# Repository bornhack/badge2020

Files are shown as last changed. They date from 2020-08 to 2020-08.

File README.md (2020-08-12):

# Bornhack Badge 2020

## About the hardware

Similar to the last couple of years, this badge has an ARM cortex M0+ as the main
controller, but on this badge it's the SAMD21 from Microchip, with 4 times as much
flash and RAM compared to the chips from the previous badges.

This makes it possible to run Adafruit CircuitPython on this badge, which lowers the
bar for how easy it is to get started hacking on the badge, since all you need is a
USB cable to connect it to your computer and an editor (vi, nano, VSCode, notepad,
you name it) to change the `code.py` file on the badge. No need to have a tool chain
installed on your computer, it's all happening on the badge when you save the file.

## Features

- The main feature of the badge is a 9x32 pixel LED matrix controlled by 2
IS31FL3731 LED controllers, that control the LEDs via charlieplexing
- The other primary feature is an infrared LED to transmit and an infrared receiver
and decoder to receive badge to badge communication
- There are also 4 navigation/game buttons and a reset button
- The badge is either powered by 2xAA batteries, that have the voltage boosted to
3.3v or via USB, where the voltage is regulated down to 3.3v
- The main controller is a SAMD21G18A with a GD25Q32C (4MB SPI flash) connected
for libraries, graphics, etc.
- There is also an unpopulated header for Shitty Add On v.1.69bis
- On the back of the badge, all i/o pins that are not used on the microcontroller
is pull out to small SMD pads for optional soldering on add-ons or similar.

## Getting started

To start making your badge your own, you can connect it via USB and a mass storage
device should show up with a `code.py` file in the root directory.

If you open that file in your favorite text editor you will find a few lines first
that loads some libraries, then some initialisation of the LED drivers and on line 20
you will find an assignment of a string variable with the scrolling text shown on
the LED matrix. To put eg. your name on the badge, you can change this text and save
the file, and after a few seconds, the badge will restart the code and your text
should be slowly scrolling across the "screen".

If you have gotten this far you are up and running with your first "hack" of the
2020 BornHack badge and you can continue with more elaborate hacking.

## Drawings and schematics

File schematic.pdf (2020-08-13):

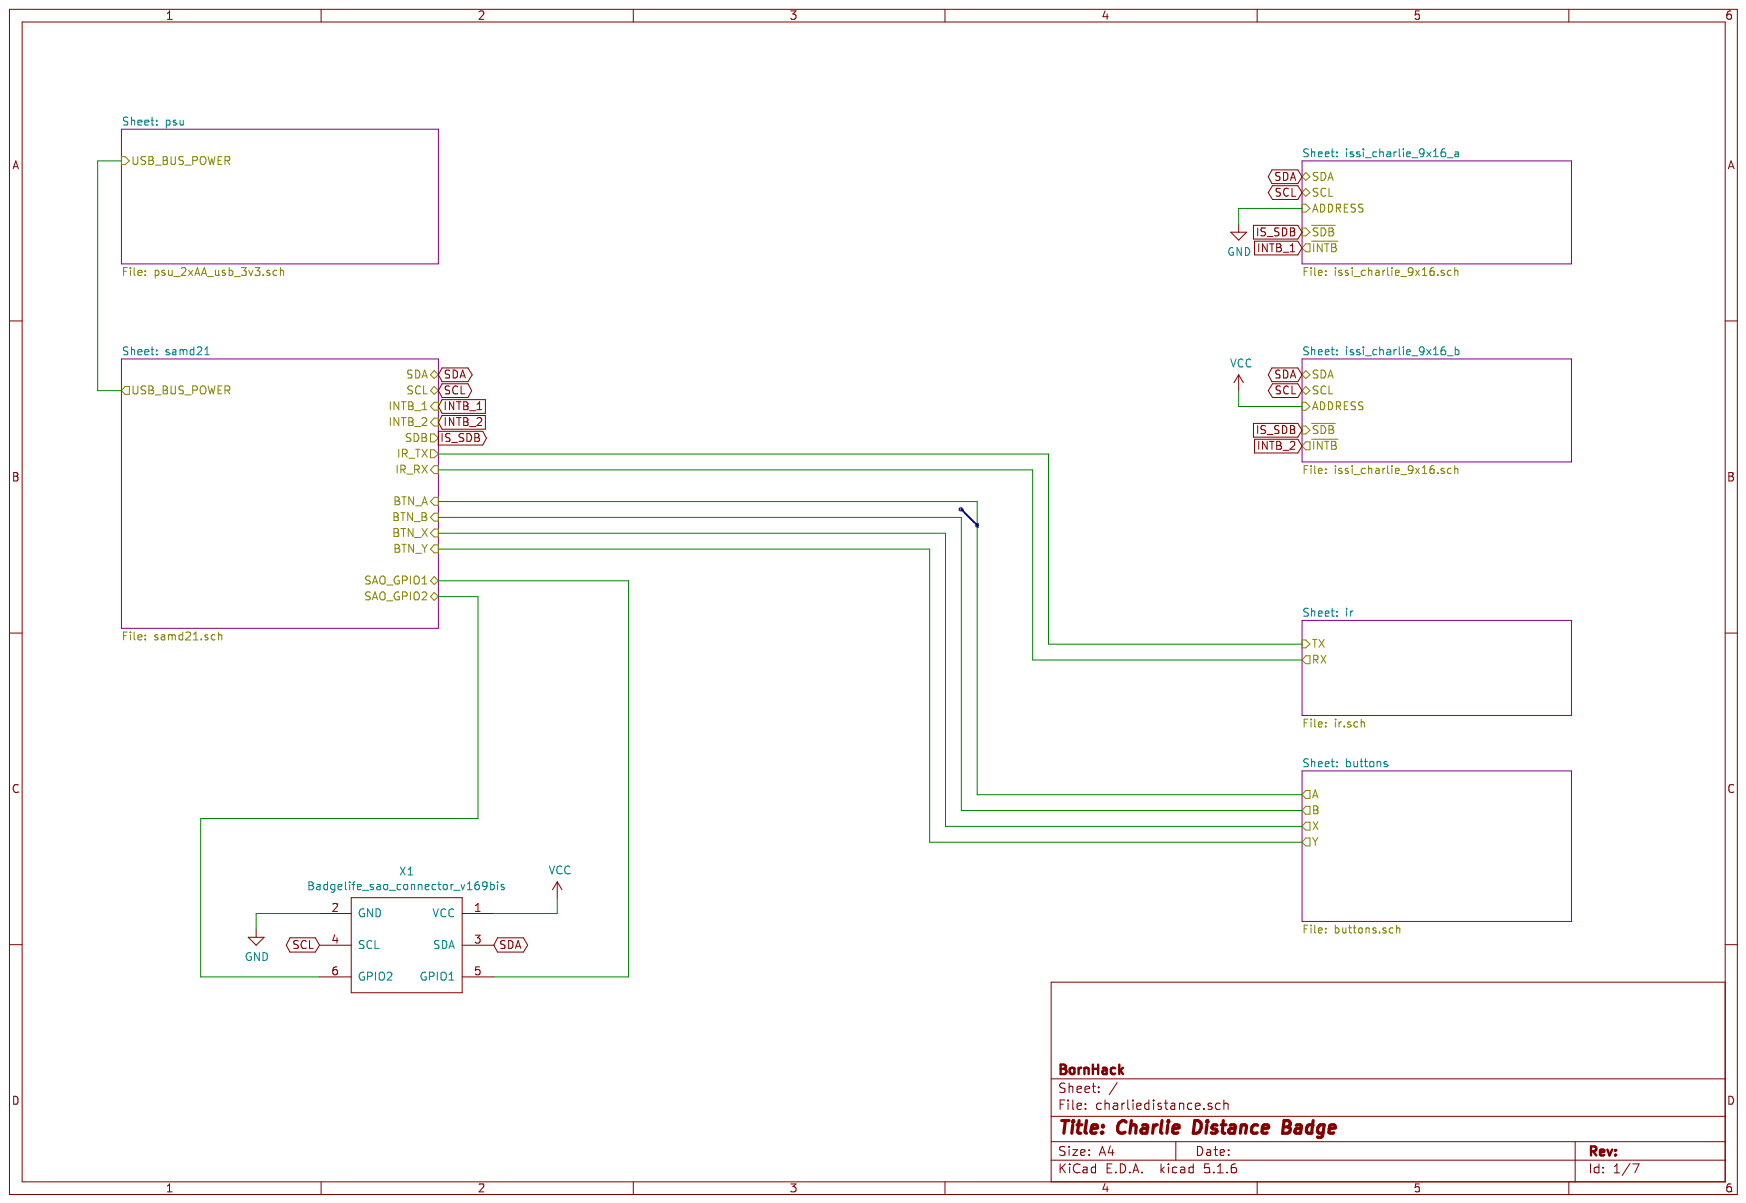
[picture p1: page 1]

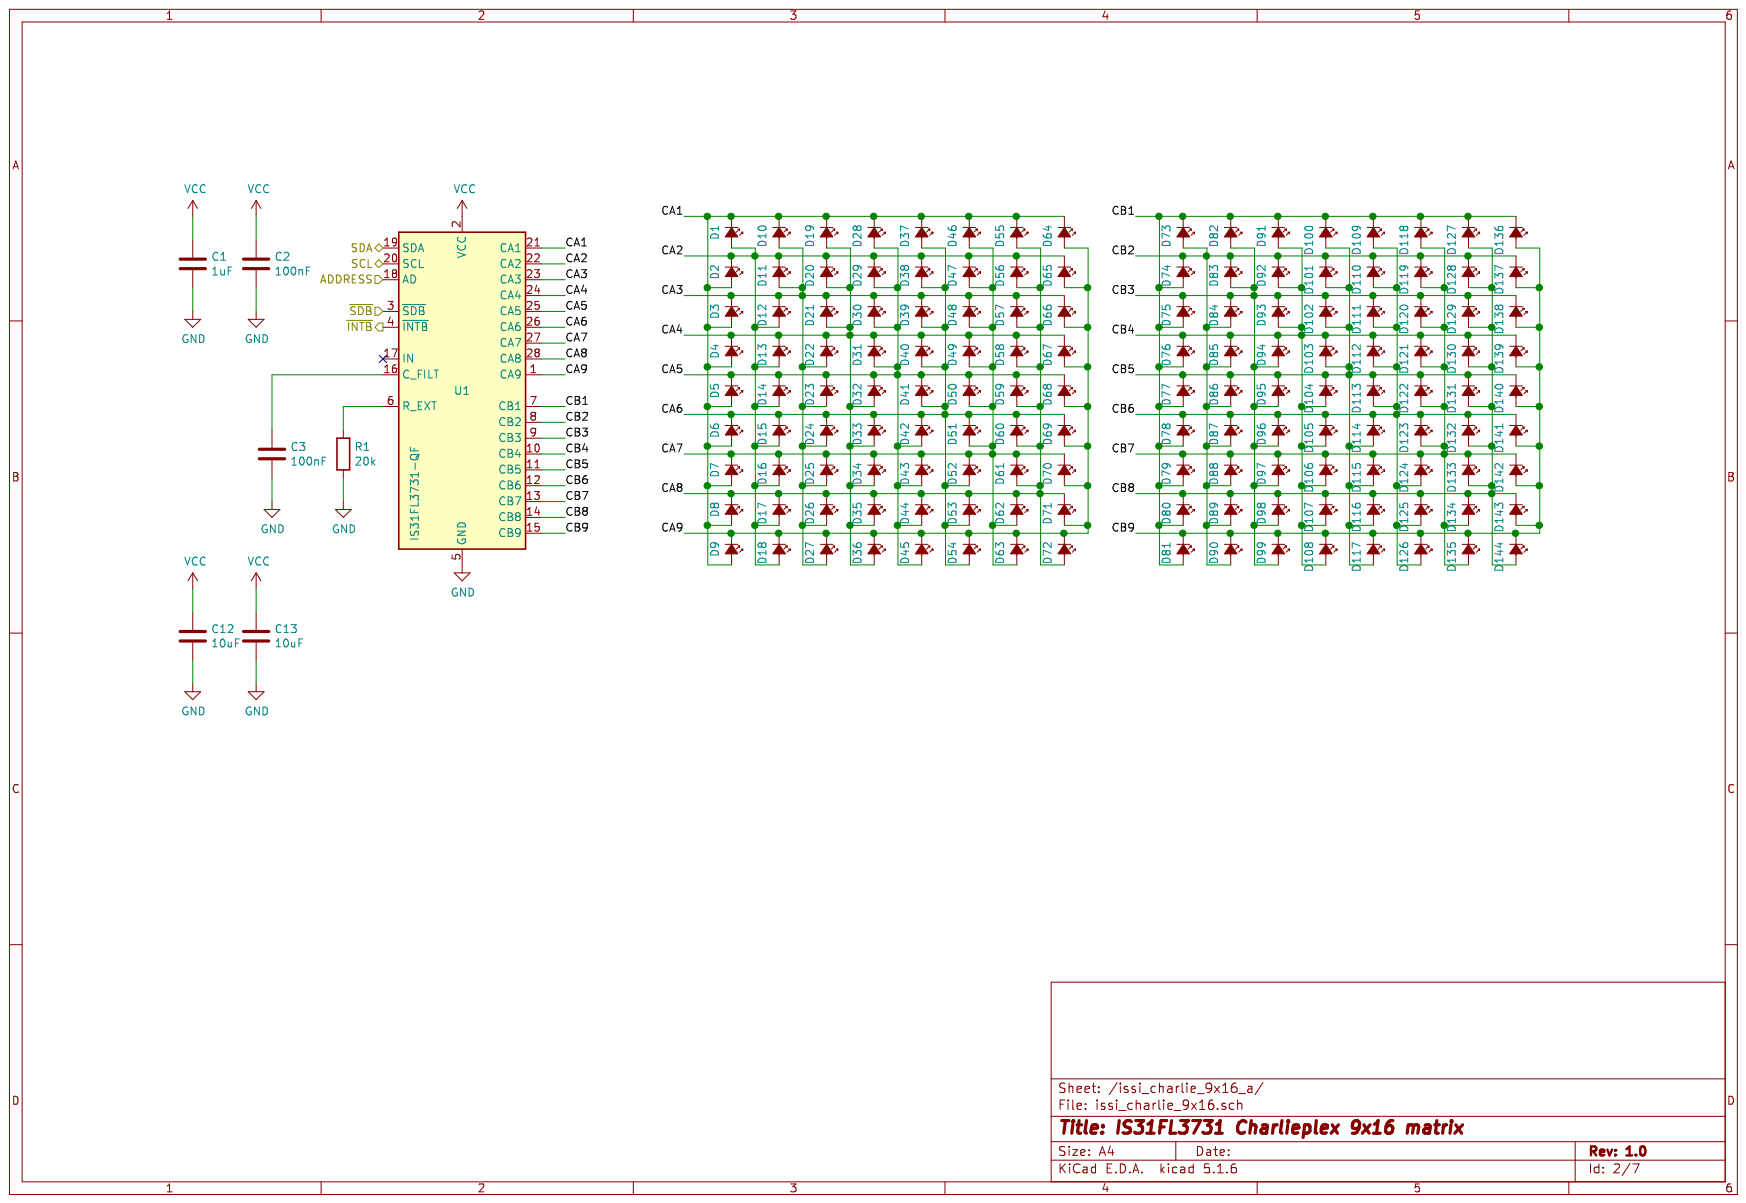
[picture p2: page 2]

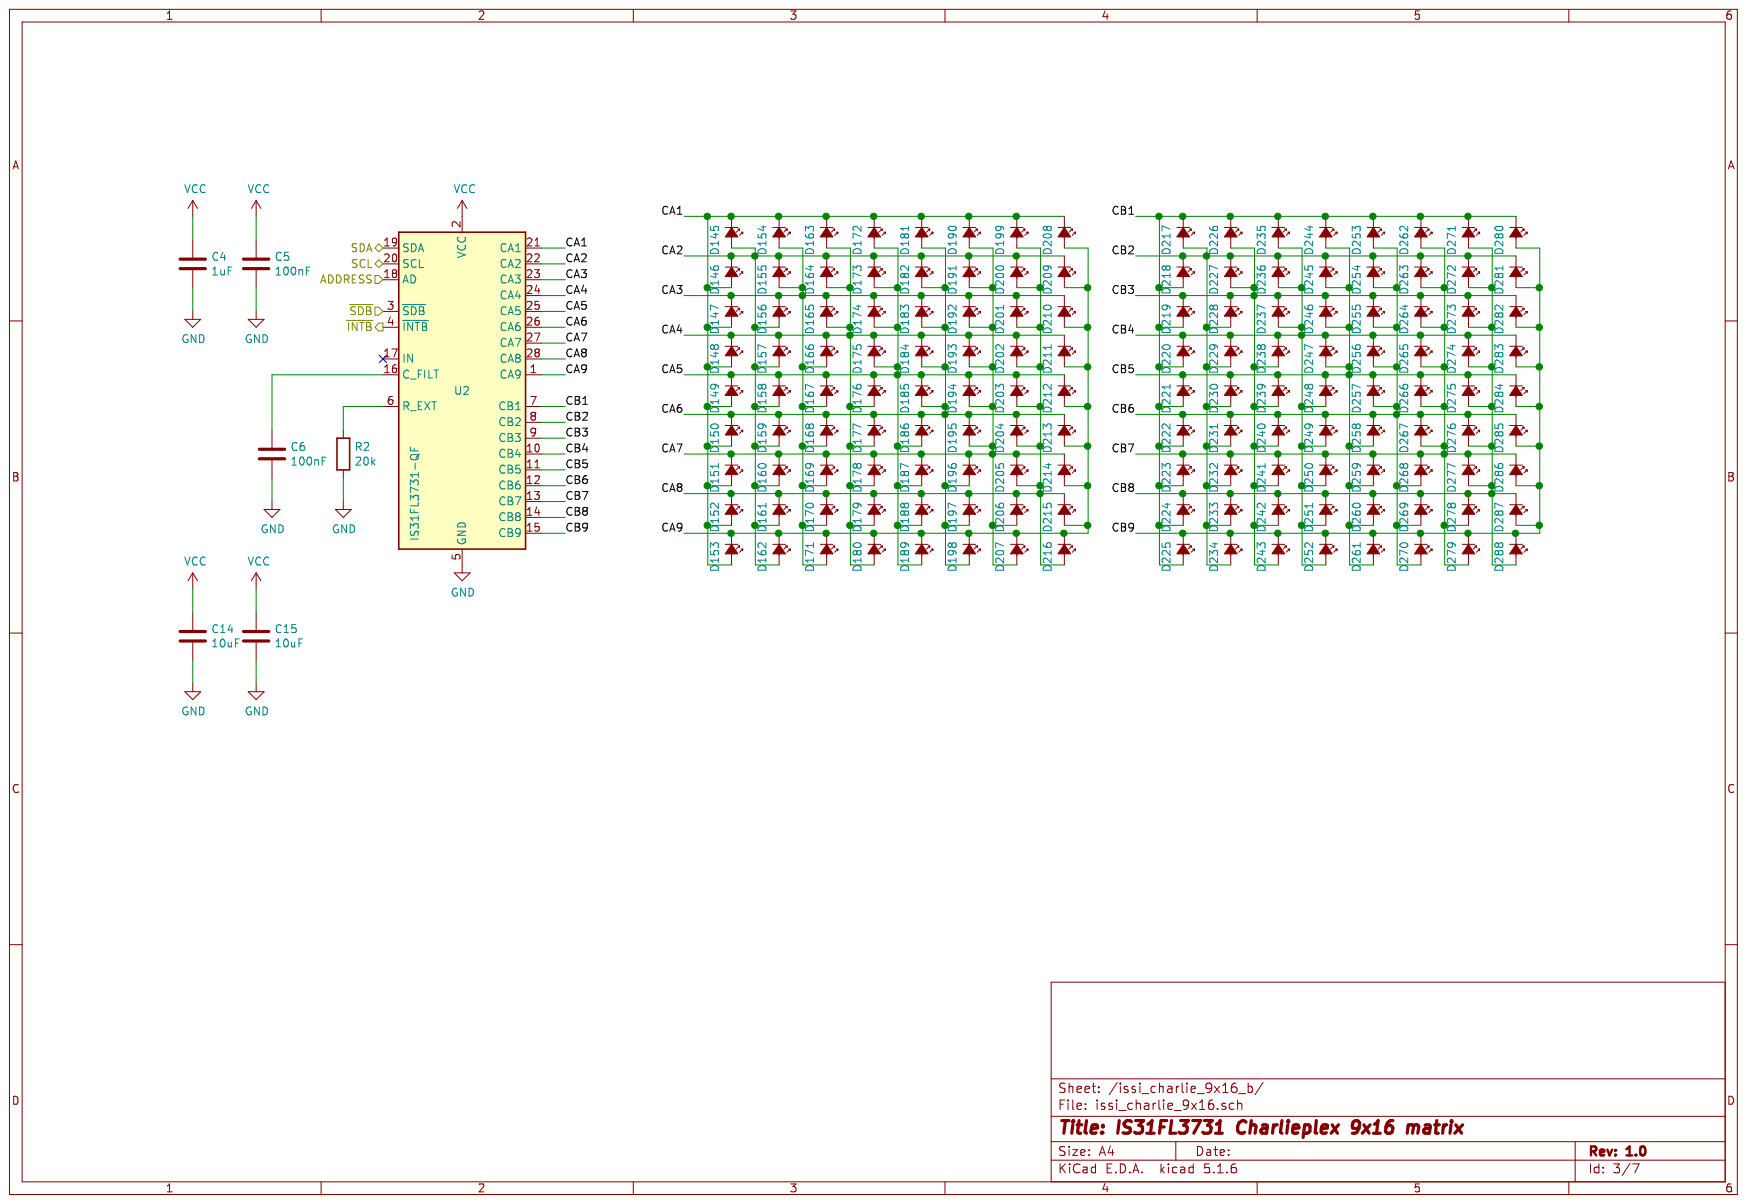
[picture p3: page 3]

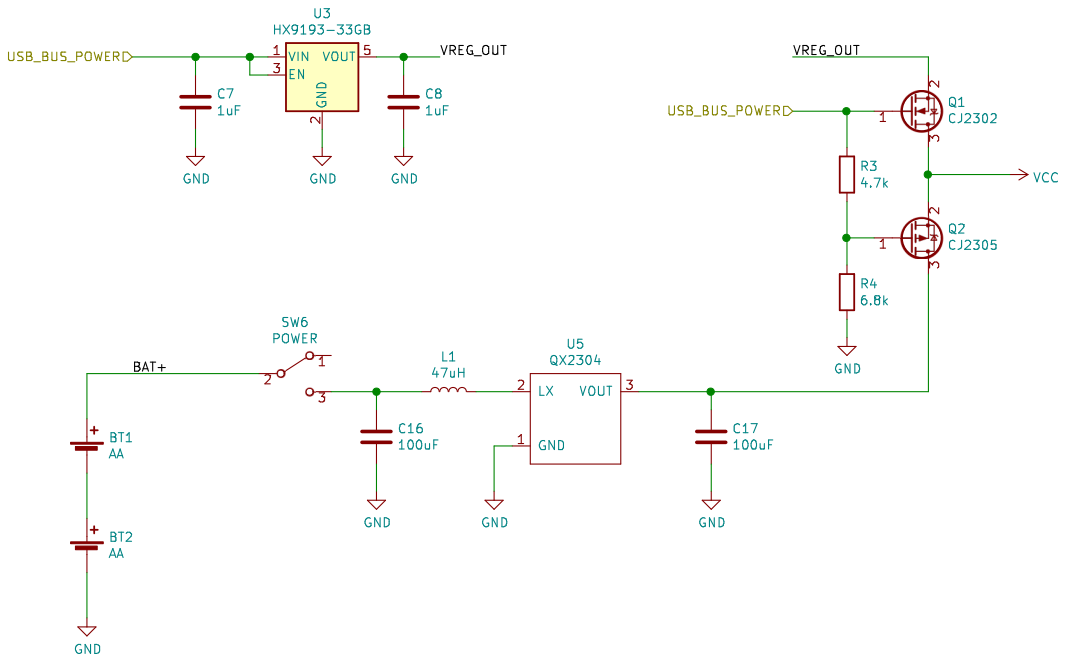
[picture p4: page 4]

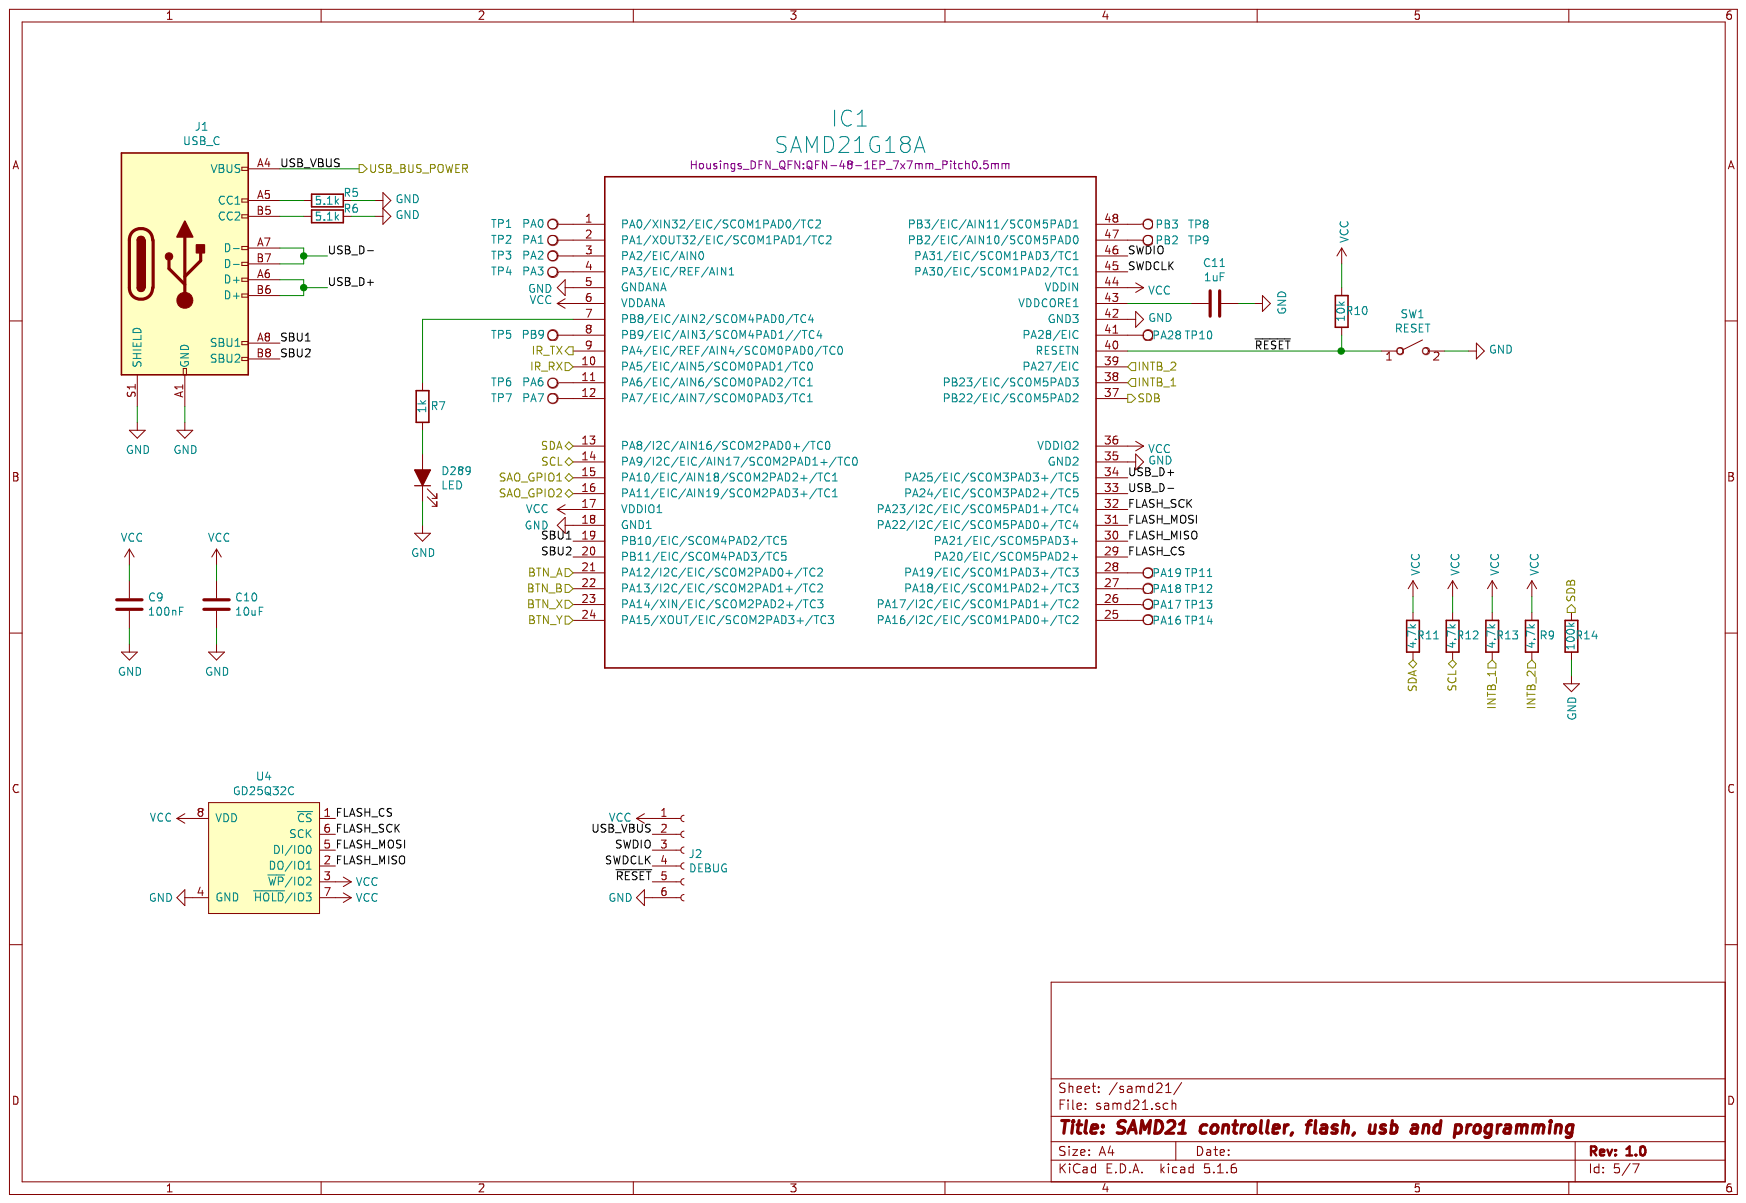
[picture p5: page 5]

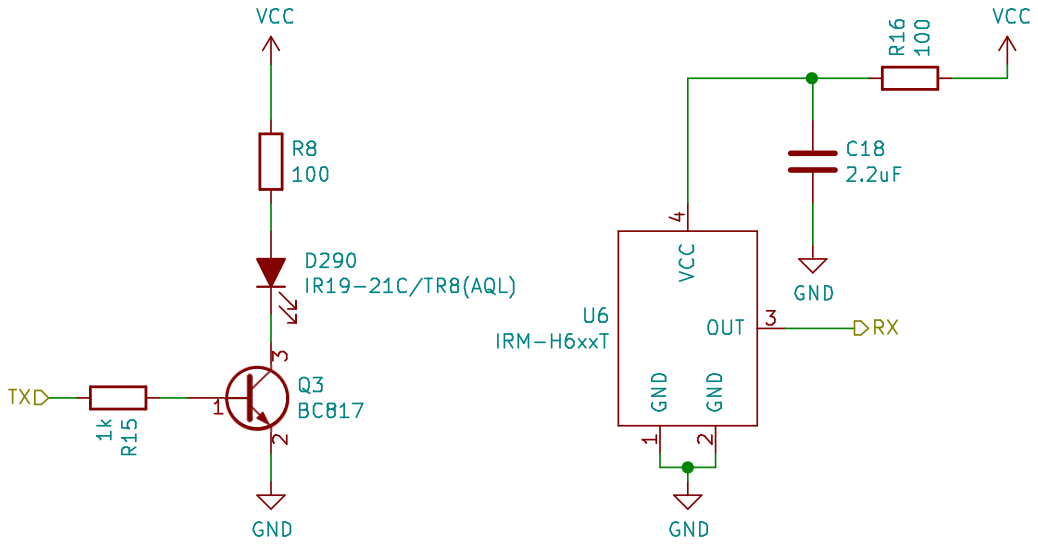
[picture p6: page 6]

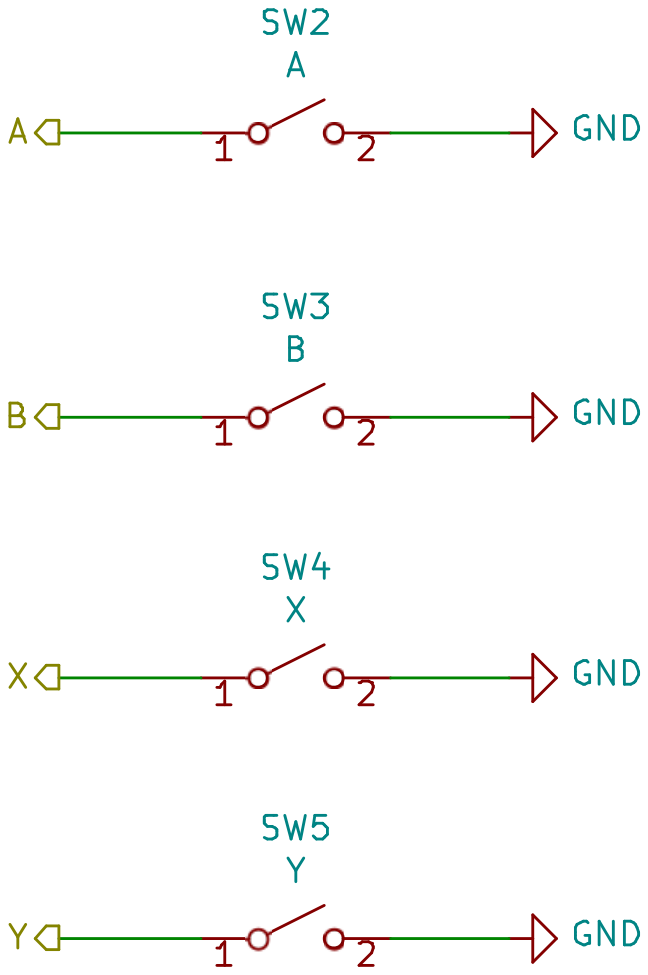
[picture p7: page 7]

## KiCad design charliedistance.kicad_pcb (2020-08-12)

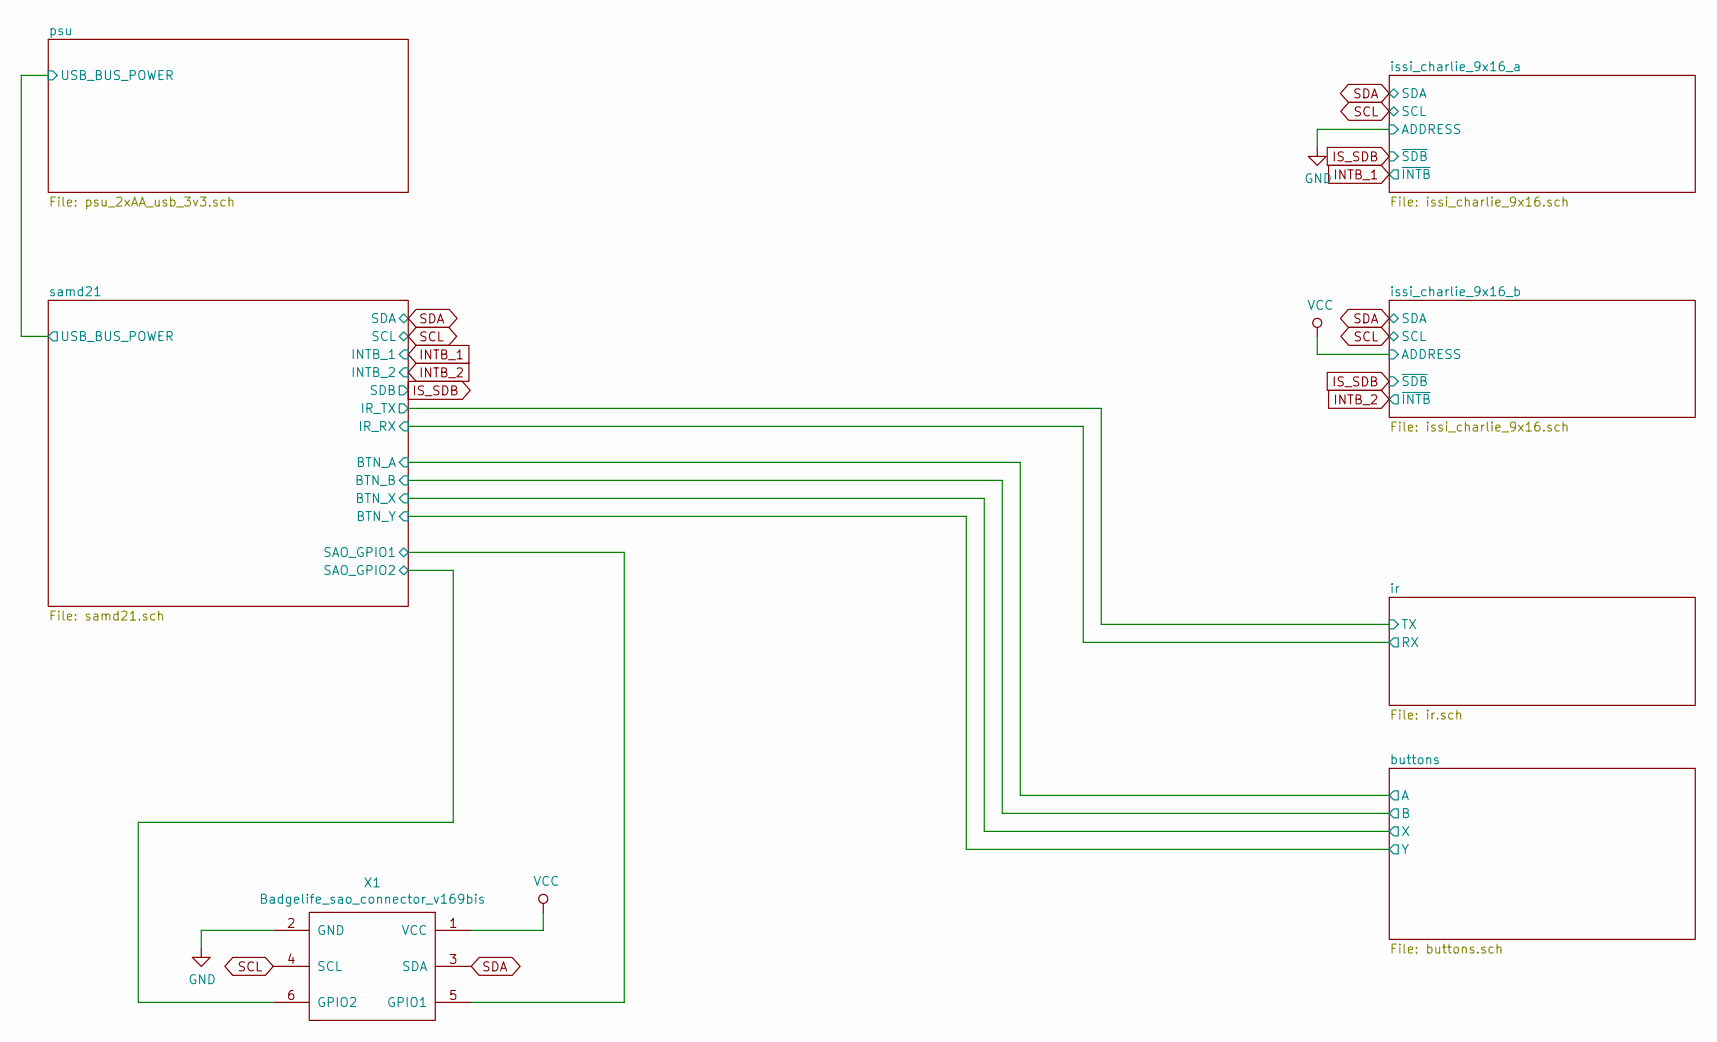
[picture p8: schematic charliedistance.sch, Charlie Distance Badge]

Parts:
X1: Badgelife_sao_connector_v169bis; Badgelife-SAOv169-BADGE-2x3

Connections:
/samd21/SAO_GPIO1: X1.5 (GPIO1); also elsewhere on the board
/samd21/SAO_GPIO2: X1.6 (GPIO2); also elsewhere on the board
GND: X1.2 (GND); also elsewhere on the board
SCL: X1.4 (SCL); also elsewhere on the board
SDA: X1.3 (SDA); also elsewhere on the board
VCC: X1.1 (VCC); also elsewhere on the board

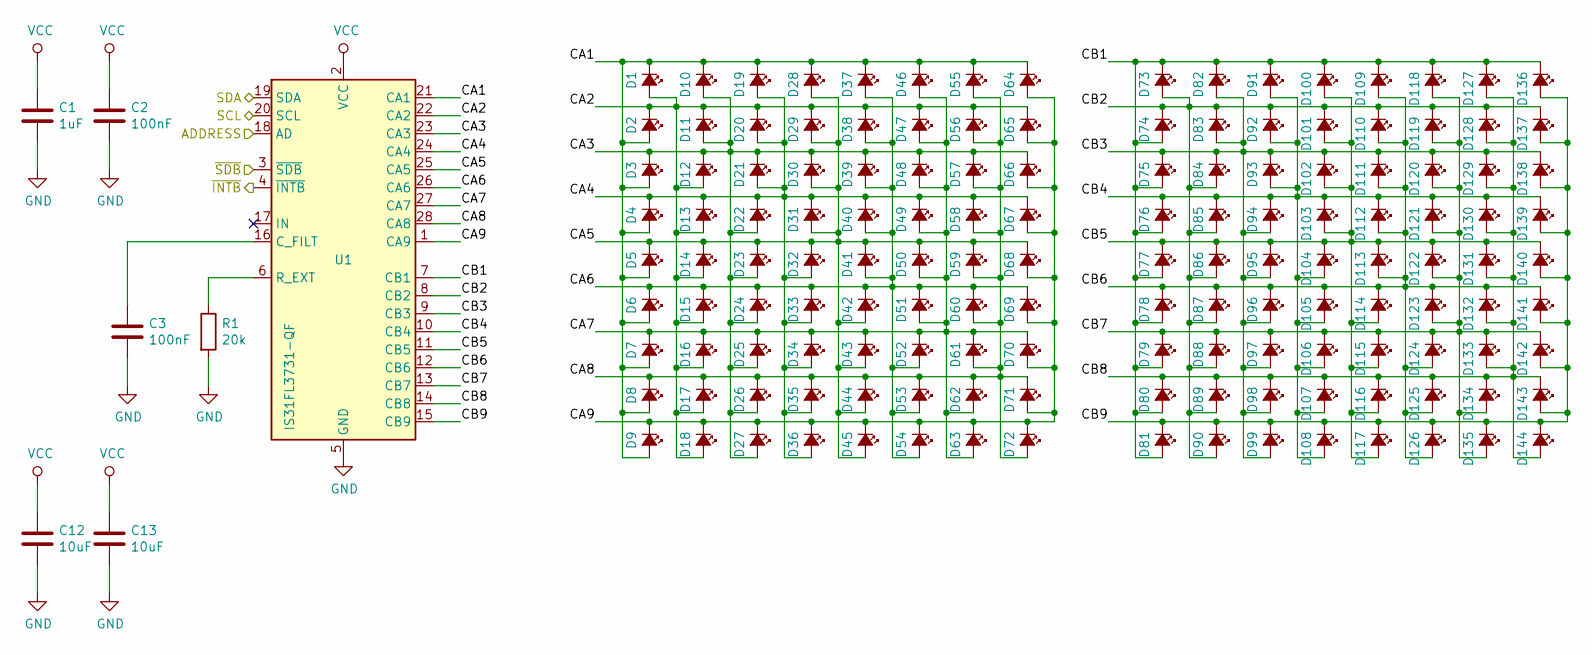
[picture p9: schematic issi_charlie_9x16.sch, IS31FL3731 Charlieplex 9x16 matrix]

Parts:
C1: 1uF; C_0603
C2, C3: 100nF; C_0603
C12, C13: 10uF; C_0603
D1, D2, D3, D4, D5, D6, D7, D8, D9, D10, D11, D12, D13, D14, D15, D16, D17, D18, D19, D20, D21, D22, D23, D24, D25, D26, D27, D28, D29, D30, D31, D32, D33, D34, D35, D36, D37, D38, D39, D40, D41, D42, D43, D44, D45, D46, D47, D48, D49, D50, D51, D52, D53, D54, D55, D56, D57, D58, D59, D60, D61, D62, D63, D64, D65, D66, D67, D68, D69, D70, D71, D72, D73, D74, D75, D76, D77, D78, D79, D80, D81, D82, D83, D84, D85, D86, D87, D88, D89, D90, D91, D92, D93, D94, D95, D96, D97, D98, D99, D100, D101, D102, D103, D104, D105, D106, D107, D108, D109, D110, D111, D112, D113, D114, D115, D116, D117, D118, D119, D120, D121, D122, D123, D124, D125, D126, D127, D128, D129, D130, D131, D132, D133, D134, D135, D136, D137, D138, D139, D140, D141, D142, D143, D144: LED_Small_ALT; LED_0603
R1: 20k; R_0603
U1: IS31FL3731-QF; QFN-28-1EP_4x4mm_Pitch0.4mm

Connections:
/issi_charlie_9x16_a/CA1: D1.1 (K), D2.2 (A), D3.2 (A), D4.2 (A), D5.2 (A), D6.2 (A), D7.2 (A), D8.2 (A), D9.2 (A), D10.1 (K), D19.1 (K), D28.1 (K), D37.1 (K), D46.1 (K), D55.1 (K), D64.1 (K), U1.21 (CA1)
/issi_charlie_9x16_a/CA2: D1.2 (A), D2.1 (K), D11.1 (K), D12.2 (A), D13.2 (A), D14.2 (A), D15.2 (A), D16.2 (A), D17.2 (A), D18.2 (A), D20.1 (K), D29.1 (K), D38.1 (K), D47.1 (K), D56.1 (K), D65.1 (K), U1.22 (CA2)
/issi_charlie_9x16_a/CA3: D3.1 (K), D10.2 (A), D11.2 (A), D12.1 (K), D21.1 (K), D22.2 (A), D23.2 (A), D24.2 (A), D25.2 (A), D26.2 (A), D27.2 (A), D30.1 (K), D39.1 (K), D48.1 (K), D57.1 (K), D66.1 (K), U1.23 (CA3)
/issi_charlie_9x16_a/CA4: D4.1 (K), D13.1 (K), D19.2 (A), D20.2 (A), D21.2 (A), D22.1 (K), D31.1 (K), D32.2 (A), D33.2 (A), D34.2 (A), D35.2 (A), D36.2 (A), D40.1 (K), D49.1 (K), D58.1 (K), D67.1 (K), U1.24 (CA4)
/issi_charlie_9x16_a/CA5: D5.1 (K), D14.1 (K), D23.1 (K), D28.2 (A), D29.2 (A), D30.2 (A), D31.2 (A), D32.1 (K), D41.1 (K), D42.2 (A), D43.2 (A), D44.2 (A), D45.2 (A), D50.1 (K), D59.1 (K), D68.1 (K), U1.25 (CA5)
/issi_charlie_9x16_a/CA6: D6.1 (K), D15.1 (K), D24.1 (K), D33.1 (K), D37.2 (A), D38.2 (A), D39.2 (A), D40.2 (A), D41.2 (A), D42.1 (K), D51.1 (K), D52.2 (A), D53.2 (A), D54.2 (A), D60.1 (K), D69.1 (K), U1.26 (CA6)
/issi_charlie_9x16_a/CA7: D7.1 (K), D16.1 (K), D25.1 (K), D34.1 (K), D43.1 (K), D46.2 (A), D47.2 (A), D48.2 (A), D49.2 (A), D50.2 (A), D51.2 (A), D52.1 (K), D61.1 (K), D62.2 (A), D63.2 (A), D70.1 (K), U1.27 (CA7)
/issi_charlie_9x16_a/CA8: D8.1 (K), D17.1 (K), D26.1 (K), D35.1 (K), D44.1 (K), D53.1 (K), D55.2 (A), D56.2 (A), D57.2 (A), D58.2 (A), D59.2 (A), D60.2 (A), D61.2 (A), D62.1 (K), D71.1 (K), D72.2 (A), U1.28 (CA8)
/issi_charlie_9x16_a/CA9: D9.1 (K), D18.1 (K), D27.1 (K), D36.1 (K), D45.1 (K), D54.1 (K), D63.1 (K), D64.2 (A), D65.2 (A), D66.2 (A), D67.2 (A), D68.2 (A), D69.2 (A), D70.2 (A), D71.2 (A), D72.1 (K), U1.1 (CA9)
/issi_charlie_9x16_a/CB1: D73.1 (K), D74.2 (A), D75.2 (A), D76.2 (A), D77.2 (A), D78.2 (A), D79.2 (A), D80.2 (A), D81.2 (A), D82.1 (K), D91.1 (K), D100.1 (K), D109.1 (K), D118.1 (K), D127.1 (K), D136.1 (K), U1.7 (CB1)
/issi_charlie_9x16_a/CB2: D73.2 (A), D74.1 (K), D83.1 (K), D84.2 (A), D85.2 (A), D86.2 (A), D87.2 (A), D88.2 (A), D89.2 (A), D90.2 (A), D92.1 (K), D101.1 (K), D110.1 (K), D119.1 (K), D128.1 (K), D137.1 (K), U1.8 (CB2)
/issi_charlie_9x16_a/CB3: D75.1 (K), D82.2 (A), D83.2 (A), D84.1 (K), D93.1 (K), D94.2 (A), D95.2 (A), D96.2 (A), D97.2 (A), D98.2 (A), D99.2 (A), D102.1 (K), D111.1 (K), D120.1 (K), D129.1 (K), D138.1 (K), U1.9 (CB3)
/issi_charlie_9x16_a/CB4: D76.1 (K), D85.1 (K), D91.2 (A), D92.2 (A), D93.2 (A), D94.1 (K), D103.1 (K), D104.2 (A), D105.2 (A), D106.2 (A), D107.2 (A), D108.2 (A), D112.1 (K), D121.1 (K), D130.1 (K), D139.1 (K), U1.10 (CB4)
/issi_charlie_9x16_a/CB5: D77.1 (K), D86.1 (K), D95.1 (K), D100.2 (A), D101.2 (A), D102.2 (A), D103.2 (A), D104.1 (K), D113.1 (K), D114.2 (A), D115.2 (A), D116.2 (A), D117.2 (A), D122.1 (K), D131.1 (K), D140.1 (K), U1.11 (CB5)
/issi_charlie_9x16_a/CB6: D78.1 (K), D87.1 (K), D96.1 (K), D105.1 (K), D109.2 (A), D110.2 (A), D111.2 (A), D112.2 (A), D113.2 (A), D114.1 (K), D123.1 (K), D124.2 (A), D125.2 (A), D126.2 (A), D132.1 (K), D141.1 (K), U1.12 (CB6)
/issi_charlie_9x16_a/CB7: D79.1 (K), D88.1 (K), D97.1 (K), D106.1 (K), D115.1 (K), D118.2 (A), D119.2 (A), D120.2 (A), D121.2 (A), D122.2 (A), D123.2 (A), D124.1 (K), D133.1 (K), D134.2 (A), D135.2 (A), D142.1 (K), U1.13 (CB7)
/issi_charlie_9x16_a/CB8: D80.1 (K), D89.1 (K), D98.1 (K), D107.1 (K), D116.1 (K), D125.1 (K), D127.2 (A), D128.2 (A), D129.2 (A), D130.2 (A), D131.2 (A), D132.2 (A), D133.2 (A), D134.1 (K), D143.1 (K), D144.2 (A), U1.14 (CB8)
/issi_charlie_9x16_a/CB9: D81.1 (K), D90.1 (K), D99.1 (K), D108.1 (K), D117.1 (K), D126.1 (K), D135.1 (K), D136.2 (A), D137.2 (A), D138.2 (A), D139.2 (A), D140.2 (A), D141.2 (A), D142.2 (A), D143.2 (A), D144.1 (K), U1.15 (CB9)
GND: C1.2, C2.2, C3.2, C12.2, C13.2, R1.2, U1.5 (GND), U1.18 (AD), U1.29 (GND); also elsewhere on the board
INTB_1: U1.4 (~INTB); also elsewhere on the board
IS_SDB: U1.3 (~SDB); also elsewhere on the board
unnamed: C3.1, U1.16 (C_FILT)
unnamed: R1.1, U1.6 (R_EXT)
SCL: U1.20 (SCL); also elsewhere on the board
SDA: U1.19 (SDA); also elsewhere on the board
VCC: C1.1, C2.1, C12.1, C13.1, U1.2 (VCC); also elsewhere on the board

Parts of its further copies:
C4: 1uF; C_0603
C5, C6: 100nF; C_0603
C14, C15: 10uF; C_0603
D145, D146, D147, D148, D149, D150, D151, D152, D153, D154, D155, D156, D157, D158, D159, D160, D161, D162, D163, D164, D165, D166, D167, D168, D169, D170, D171, D172, D173, D174, D175, D176, D177, D178, D179, D180, D181, D182, D183, D184, D185, D186, D187, D188, D189, D190, D191, D192, D193, D194, D195, D196, D197, D198, D199, D200, D201, D202, D203, D204, D205, D206, D207, D208, D209, D210, D211, D212, D213, D214, D215, D216, D217, D218, D219, D220, D221, D222, D223, D224, D225, D226, D227, D228, D229, D230, D231, D232, D233, D234, D235, D236, D237, D238, D239, D240, D241, D242, D243, D244, D245, D246, D247, D248, D249, D250, D251, D252, D253, D254, D255, D256, D257, D258, D259, D260, D261, D262, D263, D264, D265, D266, D267, D268, D269, D270, D271, D272, D273, D274, D275, D276, D277, D278, D279, D280, D281, D282, D283, D284, D285, D286, D287, D288: LED_Small_ALT; LED_0603
R2: 20k; R_0603
U2: IS31FL3731-QF; QFN-28-1EP_4x4mm_Pitch0.4mm

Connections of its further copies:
/issi_charlie_9x16_b/CA1: D145.1 (K), D146.2 (A), D147.2 (A), D148.2 (A), D149.2 (A), D150.2 (A), D151.2 (A), D152.2 (A), D153.2 (A), D154.1 (K), D163.1 (K), D172.1 (K), D181.1 (K), D190.1 (K), D199.1 (K), D208.1 (K), U2.21 (CA1)
/issi_charlie_9x16_b/CA2: D145.2 (A), D146.1 (K), D155.1 (K), D156.2 (A), D157.2 (A), D158.2 (A), D159.2 (A), D160.2 (A), D161.2 (A), D162.2 (A), D164.1 (K), D173.1 (K), D182.1 (K), D191.1 (K), D200.1 (K), D209.1 (K), U2.22 (CA2)
/issi_charlie_9x16_b/CA3: D147.1 (K), D154.2 (A), D155.2 (A), D156.1 (K), D165.1 (K), D166.2 (A), D167.2 (A), D168.2 (A), D169.2 (A), D170.2 (A), D171.2 (A), D174.1 (K), D183.1 (K), D192.1 (K), D201.1 (K), D210.1 (K), U2.23 (CA3)
/issi_charlie_9x16_b/CA4: D148.1 (K), D157.1 (K), D163.2 (A), D164.2 (A), D165.2 (A), D166.1 (K), D175.1 (K), D176.2 (A), D177.2 (A), D178.2 (A), D179.2 (A), D180.2 (A), D184.1 (K), D193.1 (K), D202.1 (K), D211.1 (K), U2.24 (CA4)
/issi_charlie_9x16_b/CA5: D149.1 (K), D158.1 (K), D167.1 (K), D172.2 (A), D173.2 (A), D174.2 (A), D175.2 (A), D176.1 (K), D185.1 (K), D186.2 (A), D187.2 (A), D188.2 (A), D189.2 (A), D194.1 (K), D203.1 (K), D212.1 (K), U2.25 (CA5)
/issi_charlie_9x16_b/CA6: D150.1 (K), D159.1 (K), D168.1 (K), D177.1 (K), D181.2 (A), D182.2 (A), D183.2 (A), D184.2 (A), D185.2 (A), D186.1 (K), D195.1 (K), D196.2 (A), D197.2 (A), D198.2 (A), D204.1 (K), D213.1 (K), U2.26 (CA6)
/issi_charlie_9x16_b/CA7: D151.1 (K), D160.1 (K), D169.1 (K), D178.1 (K), D187.1 (K), D190.2 (A), D191.2 (A), D192.2 (A), D193.2 (A), D194.2 (A), D195.2 (A), D196.1 (K), D205.1 (K), D206.2 (A), D207.2 (A), D214.1 (K), U2.27 (CA7)
/issi_charlie_9x16_b/CA8: D152.1 (K), D161.1 (K), D170.1 (K), D179.1 (K), D188.1 (K), D197.1 (K), D199.2 (A), D200.2 (A), D201.2 (A), D202.2 (A), D203.2 (A), D204.2 (A), D205.2 (A), D206.1 (K), D215.1 (K), D216.2 (A), U2.28 (CA8)
/issi_charlie_9x16_b/CA9: D153.1 (K), D162.1 (K), D171.1 (K), D180.1 (K), D189.1 (K), D198.1 (K), D207.1 (K), D208.2 (A), D209.2 (A), D210.2 (A), D211.2 (A), D212.2 (A), D213.2 (A), D214.2 (A), D215.2 (A), D216.1 (K), U2.1 (CA9)
/issi_charlie_9x16_b/CB1: D217.1 (K), D218.2 (A), D219.2 (A), D220.2 (A), D221.2 (A), D222.2 (A), D223.2 (A), D224.2 (A), D225.2 (A), D226.1 (K), D235.1 (K), D244.1 (K), D253.1 (K), D262.1 (K), D271.1 (K), D280.1 (K), U2.7 (CB1)
/issi_charlie_9x16_b/CB2: D217.2 (A), D218.1 (K), D227.1 (K), D228.2 (A), D229.2 (A), D230.2 (A), D231.2 (A), D232.2 (A), D233.2 (A), D234.2 (A), D236.1 (K), D245.1 (K), D254.1 (K), D263.1 (K), D272.1 (K), D281.1 (K), U2.8 (CB2)
/issi_charlie_9x16_b/CB3: D219.1 (K), D226.2 (A), D227.2 (A), D228.1 (K), D237.1 (K), D238.2 (A), D239.2 (A), D240.2 (A), D241.2 (A), D242.2 (A), D243.2 (A), D246.1 (K), D255.1 (K), D264.1 (K), D273.1 (K), D282.1 (K), U2.9 (CB3)
/issi_charlie_9x16_b/CB4: D220.1 (K), D229.1 (K), D235.2 (A), D236.2 (A), D237.2 (A), D238.1 (K), D247.1 (K), D248.2 (A), D249.2 (A), D250.2 (A), D251.2 (A), D252.2 (A), D256.1 (K), D265.1 (K), D274.1 (K), D283.1 (K), U2.10 (CB4)
/issi_charlie_9x16_b/CB5: D221.1 (K), D230.1 (K), D239.1 (K), D244.2 (A), D245.2 (A), D246.2 (A), D247.2 (A), D248.1 (K), D257.1 (K), D258.2 (A), D259.2 (A), D260.2 (A), D261.2 (A), D266.1 (K), D275.1 (K), D284.1 (K), U2.11 (CB5)
/issi_charlie_9x16_b/CB6: D222.1 (K), D231.1 (K), D240.1 (K), D249.1 (K), D253.2 (A), D254.2 (A), D255.2 (A), D256.2 (A), D257.2 (A), D258.1 (K), D267.1 (K), D268.2 (A), D269.2 (A), D270.2 (A), D276.1 (K), D285.1 (K), U2.12 (CB6)
/issi_charlie_9x16_b/CB7: D223.1 (K), D232.1 (K), D241.1 (K), D250.1 (K), D259.1 (K), D262.2 (A), D263.2 (A), D264.2 (A), D265.2 (A), D266.2 (A), D267.2 (A), D268.1 (K), D277.1 (K), D278.2 (A), D279.2 (A), D286.1 (K), U2.13 (CB7)
/issi_charlie_9x16_b/CB8: D224.1 (K), D233.1 (K), D242.1 (K), D251.1 (K), D260.1 (K), D269.1 (K), D271.2 (A), D272.2 (A), D273.2 (A), D274.2 (A), D275.2 (A), D276.2 (A), D277.2 (A), D278.1 (K), D287.1 (K), D288.2 (A), U2.14 (CB8)
/issi_charlie_9x16_b/CB9: D225.1 (K), D234.1 (K), D243.1 (K), D252.1 (K), D261.1 (K), D270.1 (K), D279.1 (K), D280.2 (A), D281.2 (A), D282.2 (A), D283.2 (A), D284.2 (A), D285.2 (A), D286.2 (A), D287.2 (A), D288.1 (K), U2.15 (CB9)
GND: C4.2, C5.2, C6.2, C14.2, C15.2, R2.2, U2.5 (GND), U2.29 (GND); also elsewhere on the board
INTB_2: U2.4 (~INTB); also elsewhere on the board
IS_SDB: U2.3 (~SDB); also elsewhere on the board
unnamed: C6.1, U2.16 (C_FILT)
unnamed: R2.1, U2.6 (R_EXT)
SCL: U2.20 (SCL); also elsewhere on the board
SDA: U2.19 (SDA); also elsewhere on the board
VCC: C4.1, C5.1, C14.1, C15.1, U2.2 (VCC), U2.18 (AD); also elsewhere on the board

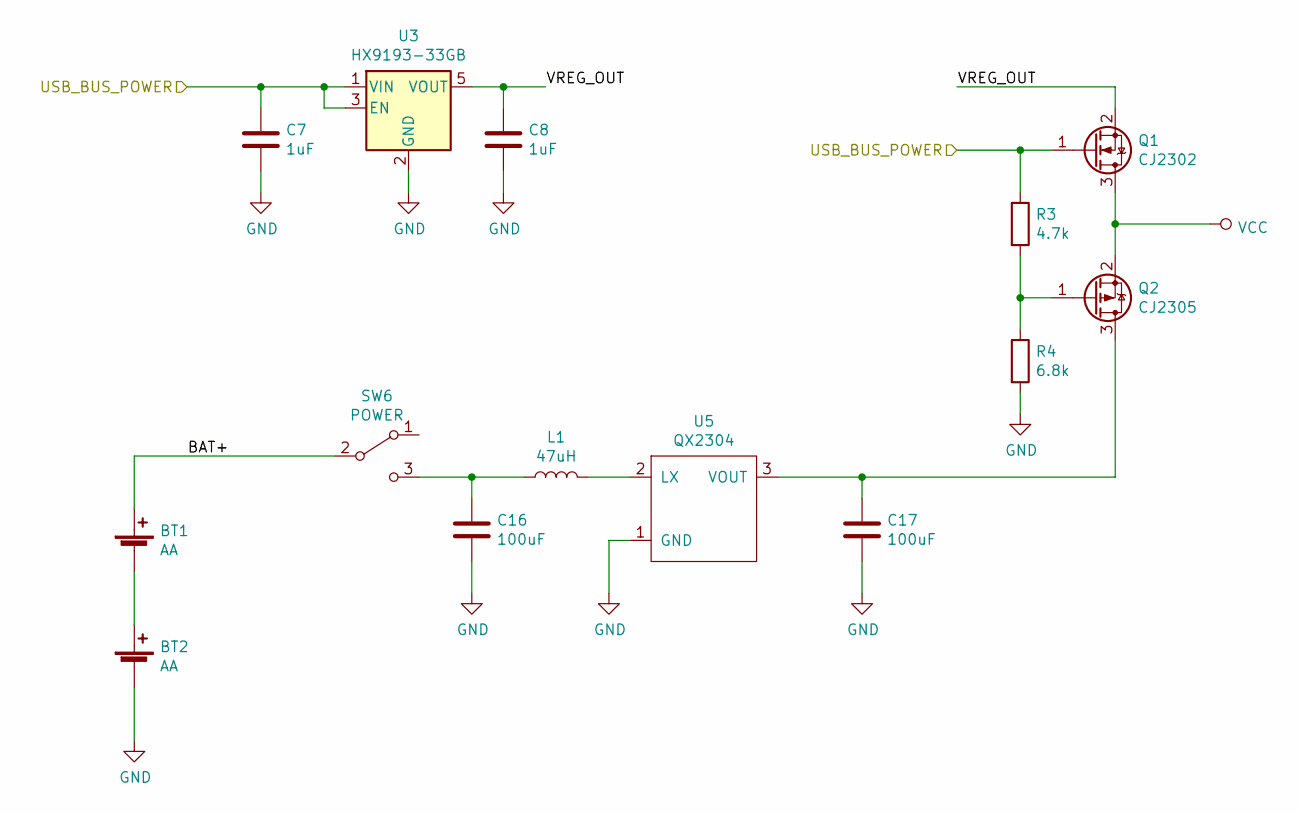
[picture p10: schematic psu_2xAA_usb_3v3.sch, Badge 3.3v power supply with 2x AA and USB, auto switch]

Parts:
BT1, BT2: AA; Single_AA
C7, C8: 1uF; C_0603
C16, C17: 100uF; C_1206
L1: 47uH; L_1210
Q1: CJ2302; SOT-23
Q2: CJ2305; SOT-23
R3: 4.7k; R_0603
R4: 6.8k; R_0603
SW6: POWER; SW_SPDT_PCM12
U3: HX9193-33GB; SOT-23-5
U5: QX2304; SOT-23

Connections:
/psu/BAT+: BT1.1 (+), SW6.2 (B)
/psu/USB_BUS_POWER: C7.1, Q1.1 (G), R3.1, U3.1 (VIN), U3.3 (EN); also elsewhere on the board
/psu/VREG_OUT: C8.1, Q1.2 (S), U3.5 (VOUT)
GND: BT2.2 (-), C7.2, C8.2, C16.2, C17.2, R4.2, U3.2 (GND), U5.1 (GND); also elsewhere on the board
unnamed: BT1.2 (-), BT2.1 (+)
unnamed: C16.1, L1.1, SW6.3 (C)
unnamed: C17.1, Q2.3 (D), U5.3 (VOUT)
unnamed: L1.2, U5.2 (LX)
unnamed: Q2.1 (G), R3.2, R4.1
VCC: Q1.3 (D), Q2.2 (S); also elsewhere on the board

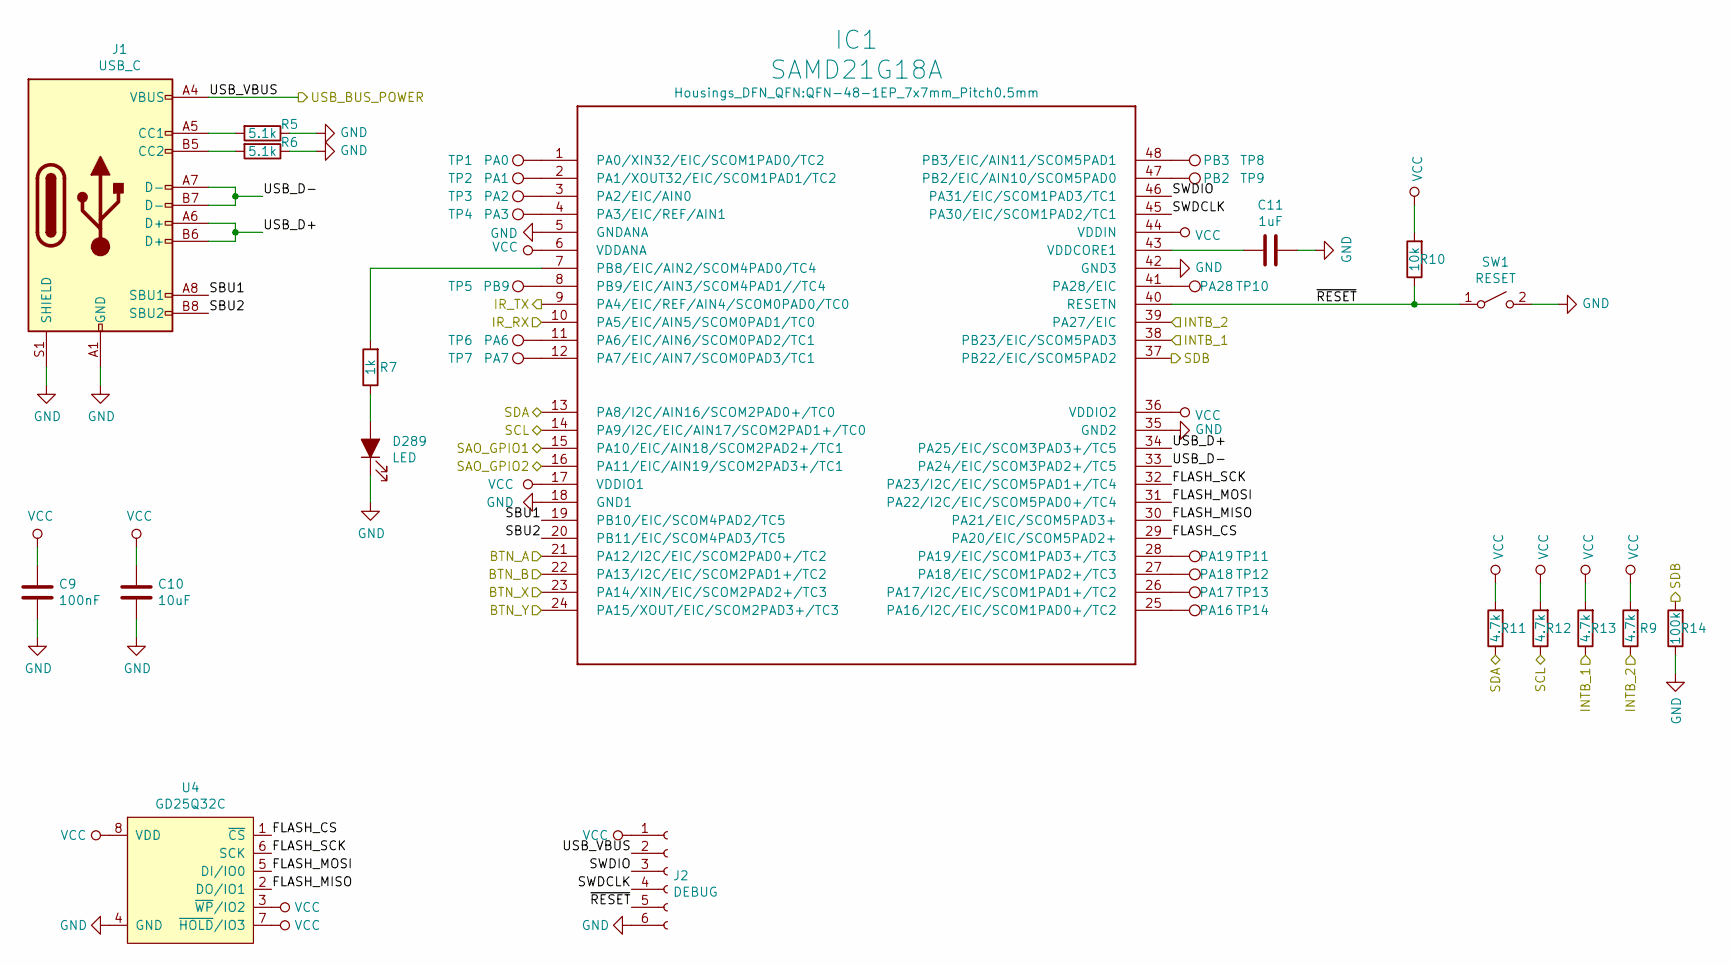
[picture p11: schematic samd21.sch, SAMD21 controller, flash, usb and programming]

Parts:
C9: 100nF; C_0603
C10: 10uF; C_0603
C11: 1uF; C_0603
D289: LED; LED_0603
IC1: SAMD21G18A; QFN-48-1EP_7x7mm_Pitch0.5mm
J1: USB_C; USB_C_Receptacle_U262-161N-4BVC11
J2: DEBUG; Pin_Header_Straight_1x06_Pitch2.54mm
R5, R6: 5.1k; R_0603
R7: 1k; R_0603
R9, R11, R12, R13: 4.7k; R_0603
R10: 10k; R_0603
R14: 100k; R_0603
SW1: RESET; SW_SPST_TL3342
TP1: PA0; TestPoint_Large
TP2: PA1; TestPoint_Large
TP3: PA2; TestPoint_Large
TP4: PA3; TestPoint_Large
TP5: PB9; TestPoint_Large
TP6: PA6; TestPoint_Large
TP7: PA7; TestPoint_Large
TP8: PB3; TestPoint_Large
TP9: PB2; TestPoint_Large
TP10: PA28; TestPoint_Large
TP11: PA19; TestPoint_Large
TP12: PA18; TestPoint_Large
TP13: PA17; TestPoint_Large
TP14: PA16; TestPoint_Large
U4: GD25Q32C; SOIC-8-1EP_3.9x4.9mm_Pitch1.27mm

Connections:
/buttons/A: IC1.21 (PA12/I2C/EIC/SCOM2PAD0+/TC2); also elsewhere on the board
/buttons/B: IC1.22 (PA13/I2C/EIC/SCOM2PAD1+/TC2); also elsewhere on the board
/psu/USB_BUS_POWER: J1.A4 (VBUS), J1.A9 (VBUS), J1.B4 (VBUS), J1.B9 (VBUS), J2.2; also elsewhere on the board
/samd21/BTN_X: IC1.23 (PA14/XIN/EIC/SCOM2PAD2+/TC3); also elsewhere on the board
/samd21/BTN_Y: IC1.24 (PA15/XOUT/EIC/SCOM2PAD3+/TC3); also elsewhere on the board
/samd21/FLASH_CS: IC1.29 (PA20/EIC/SCOM5PAD2+), U4.1 (~CS~)
/samd21/FLASH_MISO: IC1.30 (PA21/EIC/SCOM5PAD3+), U4.2 (DO/IO1)
/samd21/FLASH_MOSI: IC1.31 (PA22/I2C/EIC/SCOM5PAD0+/TC4), U4.5 (DI/IO0)
/samd21/FLASH_SCK: IC1.32 (PA23/I2C/EIC/SCOM5PAD1+/TC4), U4.6 (SCK)
/samd21/IR_RX: IC1.10 (PA5/EIC/AIN5/SCOM0PAD1/TC0); also elsewhere on the board
/samd21/IR_TX: IC1.9 (PA4/EIC/REF/AIN4/SCOM0PAD0/TC0); also elsewhere on the board
/samd21/SAO_GPIO1: IC1.15 (PA10/EIC/AIN18/SCOM2PAD2+/TC1); also elsewhere on the board
/samd21/SAO_GPIO2: IC1.16 (PA11/EIC/AIN19/SCOM2PAD3+/TC1); also elsewhere on the board
/samd21/SBU1: IC1.19 (PB10/EIC/SCOM4PAD2/TC5), J1.A8 (SBU1)
/samd21/SBU2: IC1.20 (PB11/EIC/SCOM4PAD3/TC5), J1.B8 (SBU2)
/samd21/SWDCLK: IC1.45 (PA30/EIC/SCOM1PAD2/TC1), J2.4
/samd21/SWDIO: IC1.46 (PA31/EIC/SCOM1PAD3/TC1), J2.3
/samd21/USB_D+: IC1.34 (PA25/EIC/SCOM3PAD3+/TC5), J1.A6 (D+), J1.B6 (D+)
/samd21/USB_D-: IC1.33 (PA24/EIC/SCOM3PAD2+/TC5), J1.A7 (D-), J1.B7 (D-)
/samd21/~RESET: IC1.40 (RESETN), J2.5, R10.1, SW1.1 (A)
GND: C9.2, C10.2, C11.2, D289.1 (K), IC1.5 (GNDANA), IC1.18 (GND1), IC1.35 (GND2), IC1.42 (GND3), J1.A1 (GND), J1.A12 (GND), J1.B1 (GND), J1.B12 (GND), J1.S1 (SHIELD), J2.6, R5.1, R6.1, R14.1, SW1.2 (B), U4.4 (GND); also elsewhere on the board
INTB_1: IC1.38 (PB23/EIC/SCOM5PAD3), R13.1; also elsewhere on the board
INTB_2: IC1.39 (PA27/EIC), R9.1; also elsewhere on the board
IS_SDB: IC1.37 (PB22/EIC/SCOM5PAD2), R14.2; also elsewhere on the board
unnamed: C11.1, IC1.43 (VDDCORE1)
unnamed: D289.2 (A), R7.1
unnamed: IC1.1 (PA0/XIN32/EIC/SCOM1PAD0/TC2), TP1.1
unnamed: IC1.2 (PA1/XOUT32/EIC/SCOM1PAD1/TC2), TP2.1
unnamed: IC1.3 (PA2/EIC/AIN0), TP3.1
unnamed: IC1.4 (PA3/EIC/REF/AIN1), TP4.1
unnamed: IC1.7 (PB8/EIC/AIN2/SCOM4PAD0/TC4), R7.2
unnamed: IC1.8 (PB9/EIC/AIN3/SCOM4PAD1//TC4), TP5.1
unnamed: IC1.11 (PA6/EIC/AIN6/SCOM0PAD2/TC1), TP6.1
unnamed: IC1.12 (PA7/EIC/AIN7/SCOM0PAD3/TC1), TP7.1
unnamed: IC1.25 (PA16/I2C/EIC/SCOM1PAD0+/TC2), TP14.1
unnamed: IC1.26 (PA17/I2C/EIC/SCOM1PAD1+/TC2), TP13.1
unnamed: IC1.27 (PA18/EIC/SCOM1PAD2+/TC3), TP12.1
unnamed: IC1.28 (PA19/EIC/SCOM1PAD3+/TC3), TP11.1
unnamed: IC1.41 (PA28/EIC), TP10.1
unnamed: IC1.47 (PB2/EIC/AIN10/SCOM5PAD0), TP9.1
unnamed: IC1.48 (PB3/EIC/AIN11/SCOM5PAD1), TP8.1
unnamed: J1.A5 (CC1), R5.2
unnamed: J1.B5 (CC2), R6.2
SCL: IC1.14 (PA9/I2C/EIC/AIN17/SCOM2PAD1+/TC0), R12.1; also elsewhere on the board
SDA: IC1.13 (PA8/I2C/AIN16/SCOM2PAD0+/TC0), R11.1; also elsewhere on the board
VCC: C9.1, C10.1, IC1.6 (VDDANA), IC1.17 (VDDIO1), IC1.36 (VDDIO2), IC1.44 (VDDIN), J2.1, R9.2, R10.2, R11.2, R12.2, R13.2, U4.3 (~WP~/IO2), U4.7 (~HOLD~/IO3), U4.8 (VDD); also elsewhere on the board

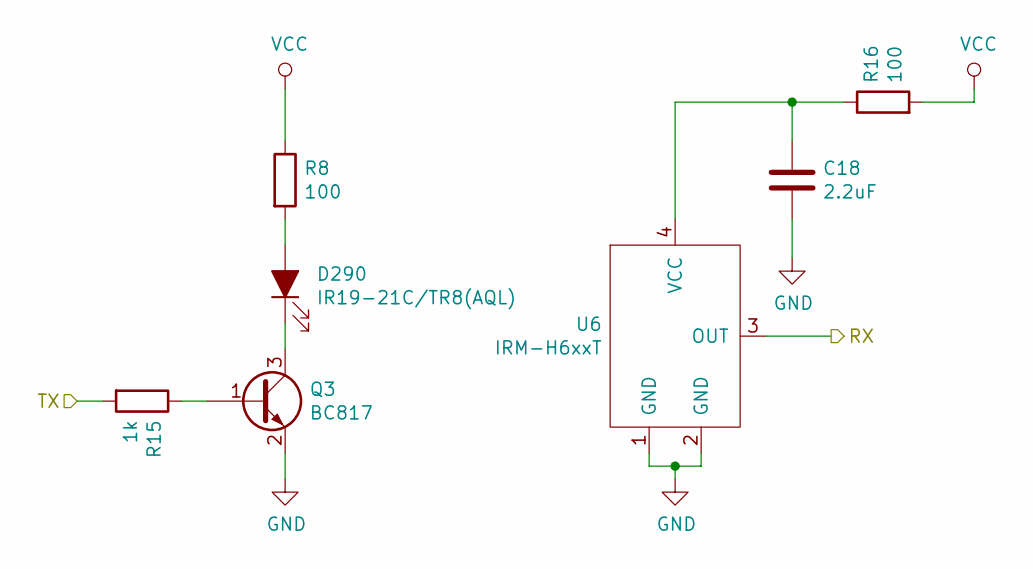
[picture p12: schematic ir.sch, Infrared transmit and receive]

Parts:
C18: 2.2uF; C_0603
D290: IR19-21C/TR8(AQL); LED_0603
Q3: BC817; SOT-23
R8, R16: 100; R_0603
R15: 1k; R_0603
U6: IRM-H6xxT

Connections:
/samd21/IR_RX: U6.3 (OUT); also elsewhere on the board
/samd21/IR_TX: R15.2; also elsewhere on the board
GND: C18.2, Q3.2 (E), U6.1 (GND), U6.2 (GND); also elsewhere on the board
unnamed: C18.1, R16.1, U6.4 (VCC)
unnamed: D290.1 (K), Q3.3 (C)
unnamed: D290.2 (A), R8.2
unnamed: Q3.1 (B), R15.1
VCC: R8.1, R16.2; also elsewhere on the board

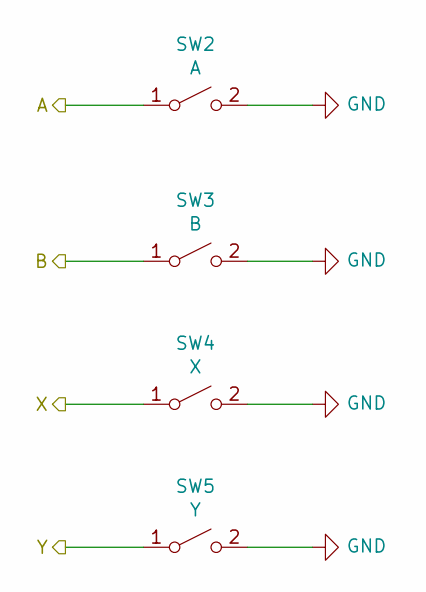
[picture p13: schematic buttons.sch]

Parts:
SW2: A; SW_SPST_TS3625A-HT
SW3: B; SW_SPST_TS3625A-HT
SW4: X; SW_SPST_TS3625A-HT
SW5: Y; SW_SPST_TS3625A-HT

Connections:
/buttons/A: SW2.1 (A); also elsewhere on the board
/buttons/B: SW3.1 (A); also elsewhere on the board
/samd21/BTN_X: SW4.1 (A); also elsewhere on the board
/samd21/BTN_Y: SW5.1 (A); also elsewhere on the board
GND: SW2.2 (B), SW3.2 (B), SW4.2 (B), SW5.2 (B); also elsewhere on the board

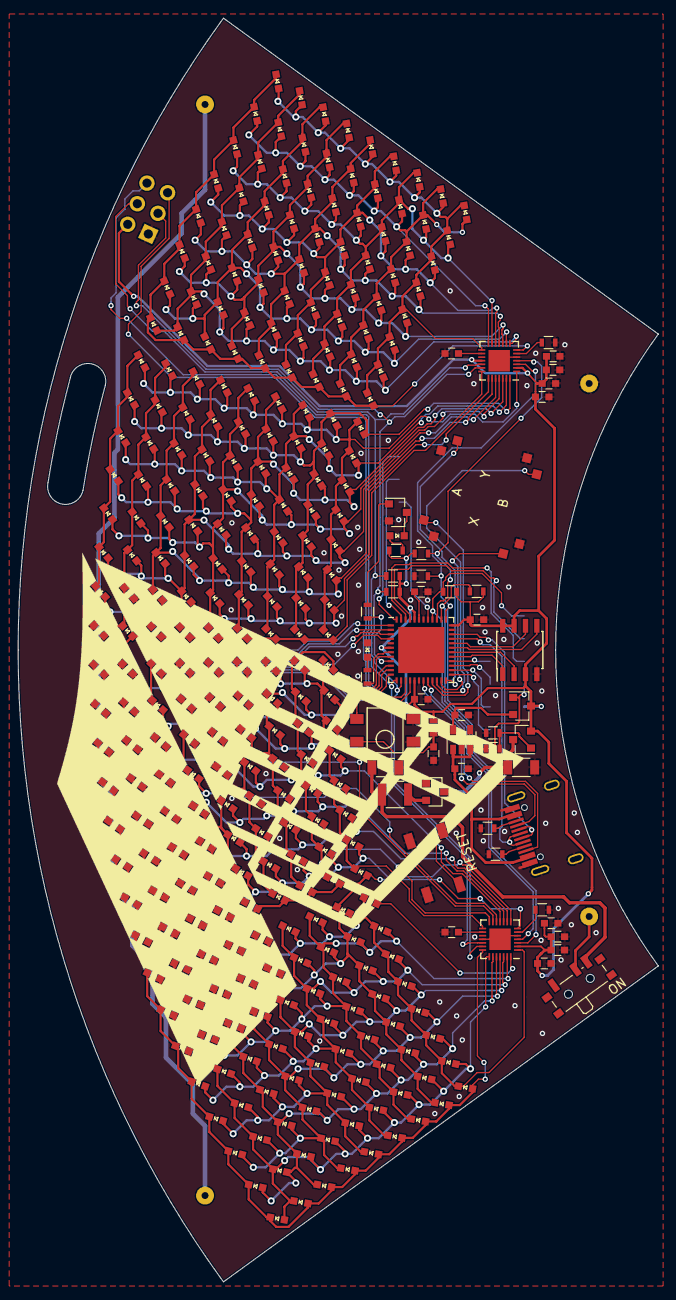
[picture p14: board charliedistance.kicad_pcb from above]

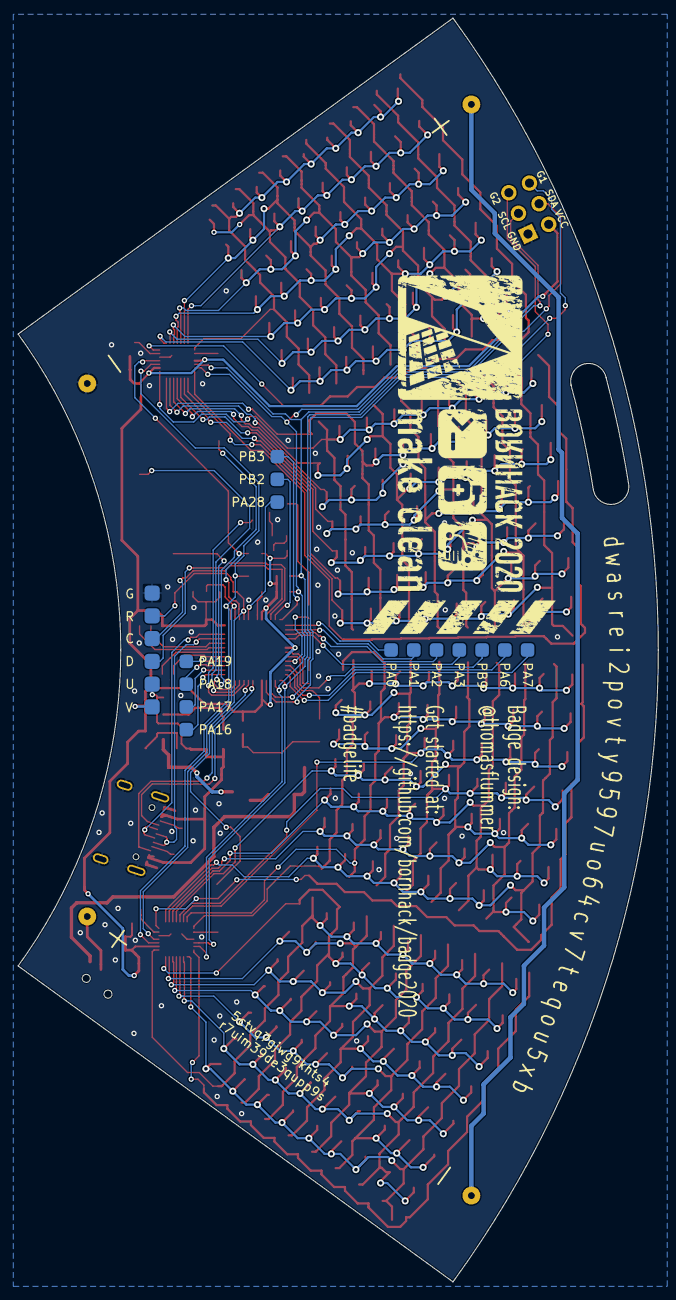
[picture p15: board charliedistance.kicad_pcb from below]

Board: 2 copper layers, 71.5 x 141.1 mm, 360 parts (17 on the bottom side), 97 nets.

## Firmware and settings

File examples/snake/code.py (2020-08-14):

import board
from digitalio import DigitalInOut, Pull
from digitalio import DigitalInOut, Direction, Pull
import time
import busio
import adafruit_framebuf
import adafruit_is31fl3731
from random import randint

numbers = [
    [0b0000, 0b0110, 0b1001, 0b1001, 0b1001, 0b1001, 0b1001, 0b0110, 0b0000,],
    [0b0000, 0b0010, 0b0110, 0b0010, 0b0010, 0b0010, 0b0010, 0b0111, 0b0000,],
    [0b0000, 0b0110, 0b1001, 0b1001, 0b0001, 0b0010, 0b0100, 0b1111, 0b0000,],
    [0b0000, 0b0110, 0b1001, 0b0001, 0b0011, 0b0001, 0b1001, 0b0110, 0b0000,],
    [0b0000, 0b0011, 0b0101, 0b1001, 0b1111, 0b0001, 0b0001, 0b0001, 0b0000,],
    [0b0000, 0b1111, 0b1000, 0b1000, 0b1110, 0b0001, 0b0001, 0b1110, 0b0000,],
    [0b0000, 0b0110, 0b1001, 0b1000, 0b0110, 0b1001, 0b1001, 0b0110, 0b0000,],
    [0b0000, 0b1111, 0b0001, 0b0001, 0b0010, 0b0100, 0b0100, 0b1000, 0b0000,],
    [0b0000, 0b0110, 0b1001, 0b1001, 0b0110, 0b1001, 0b1001, 0b0110, 0b0000,],
    [0b0000, 0b0110, 0b1001, 0b1001, 0b0110, 0b0001, 0b1001, 0b0110, 0b0000,],
]

# configure I2C
i2c = busio.I2C(board.SCL, board.SDA)

# turn on LED drivers
sdb = DigitalInOut(board.SDB)
sdb.direction = Direction.OUTPUT
sdb.value = True

# set up the two LED drivers
display = adafruit_is31fl3731.Matrix(i2c, address=0x74)
display2 = adafruit_is31fl3731.Matrix(i2c, address=0x77)


btnA = DigitalInOut(board.BTNA)
btnA.pull = Pull.UP
btnB = DigitalInOut(board.BTNB)
btnB.pull = Pull.UP
btnX = DigitalInOut(board.BTNX)
btnX.pull = Pull.UP
btnY = DigitalInOut(board.BTNY)
btnY.pull = Pull.UP

print(f"screen width: {display.width}")
print(f"screen height: {display.height}")


def spawn_food():
    global food
    food = (randint(0, display.width * 2 - 1), randint(0, display.height - 1))


def set_pixel(pixel, brightness):
    if pixel[0] > display.width - 1:
        display2.pixel(pixel[0] - display.width, pixel[1], brightness)
    else:
        display.pixel(pixel[0], pixel[1], brightness)


def clear():
    display.fill(0)
    display2.fill(0)


def draw_food():
    set_pixel(food, 255)


def move():
    global score
    global last_move
    last_move = time.monotonic()
    prev_head = body[-1]
    if direction == 2:
        head = prev_head[0] % 32, (prev_head[1] - 1) % 9
    elif direction == -2:
        head = prev_head[0] % 32, (prev_head[1] + 1) % 9
    elif direction == 1:
        head = (prev_head[0] + 1) % 32, prev_head[1] % 9
    elif direction == -1:
        head = (prev_head[0] - 1) % 32, prev_head[1] % 9
    # delete tail
    if head == food:
        # food eaten!
        set_pixel(food, 0)
        score += 1
        draw_score()
        spawn_food()
    else:
        # delete tail
        set_pixel(body[0], 0)
        del body[0]
    # DEATH
    if head in body:
        clear()
        exit()

    set_pixel(head, 15)
    body.append(head)


def handle_input():
    global direction
    if not btnA.value:
        if (direction + 2) != 0:
            direction = 2
    elif not btnB.value:
        if (direction - 2) != 0:
            direction = -2
    elif not btnX.value:
        if (direction - 1) != 0:
            direction = -1
    elif not btnY.value:
        if (direction + 1) != 0:
            direction = 1


def bits(n):
    for i in reversed(range(4)):
        yield (2 ** i & n) != 0


def draw_score():
    for offset, digit in enumerate(str(score)):
        number = numbers[int(digit)]
        for y, x_row in enumerate(number):
            for x, brightness in enumerate(bits(x_row)):
                set_pixel((1 + x + offset * 5, y), brightness)


body = [(0, 0)]
# 2 = up, -2 = down, -1 = left, 1 = right
direction = 1
score = 0
frame = False
last_move = time.monotonic()

draw_score()
spawn_food()

while True:
    handle_input()
    time_since_last_move = time.monotonic() - last_move
    if time_since_last_move > 0.2:
        move()
        # draw food everytime
        draw_food()

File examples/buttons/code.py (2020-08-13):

import board
from digitalio import DigitalInOut, Pull

# Digital inputs are input by default so there is no need to specify a direction
# The button pins do need to be pulled up using the pull-up resistor built into the SAMD microcontroller

btnA = DigitalInOut(board.BTNA)
btnA.pull = Pull.UP
btnB = DigitalInOut(board.BTNB)
btnB.pull = Pull.UP
btnX = DigitalInOut(board.BTNX)
btnX.pull = Pull.UP
btnY = DigitalInOut(board.BTNY)
btnY.pull = Pull.UP

# You can read the value by looking at the variable "btnA.value", this boolean will be False when the button is being pressed
# and True when the button is not being pressed

oldA = True
oldB = True
oldX = True
oldY = True

while True:
    newA = btnA.value
    newB = btnB.value
    newX = btnX.value
    newY = btnY.value

    if newA != oldA:
        oldA = newA
        if not newA:
            print("Button A pressed!")
        else:
            print("Button A released!")

    if newB != oldB:
        oldB = newB
        if not newB:
            print("Button B pressed!")
        else:
            print("Button B released!")

    if newX != oldX:
        oldX = newX
        if not newX:
            print("Button X pressed!")
        else:
            print("Button X released!")

    if newY != oldY:
        oldY = newY
        if not newY:
            print("Button Y pressed!")
        else:
            print("Button Y released!")

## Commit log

2020-08-12 Updates to production version
    Changed infrared setup, added step-up for battery power, added battery power switch, added more capacitors, changed and added logos, etc.
    [charliedistance.kicad_pcb, charliedistance.sch, ir.sch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]
2020-08-12 Add example for buttons
2020-08-13 Add PDF version of the schematic
2020-08-13 Fixed formatting of buttons code example
    [code.py]
2020-08-13 Fixed permission and a import error in the codee
    [code.py]
